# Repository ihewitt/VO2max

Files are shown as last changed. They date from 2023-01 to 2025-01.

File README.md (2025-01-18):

# VO₂max
Code and build files for Rabbitcreek's VO₂Max Spirometer. _Incorporating CO₂ enhancements from Ulrich Rissel._
Build instructions on [Instructable](https://www.instructables.com/Accurate-VO2-Max-for-Zwift-and-Strava/)
See Nik's pages for excellent build details: [meteoscientific](https://github.com/meteoscientific/VO2max)

Source code for Arduino under "VO₂Max" - Arduino board settings to use for TTGO T-Display:

    Board: ESP32 Dev Module
    Upload Speed: 921600
    CPU Frequency: 240Mhz (WiFi/BT)
    Flash Frequency: 80Mhz
    Flash Mode: QIO
    Flash Size: 4MB (32Mb)
    Partition Scheme: Huge APP (3MB No OTA/1MB SPIFFS)
    Core Debug Level: None
    PSRAM: Disabled

<figure>
    Build parts
    <figcaption>Source parts, top to bottom. 3M mask with front plate removed, 3D printed case, Oxygen sensor, TTGo T-Display, Flow sensor.</figcaption>
</figure><br><br>
<figure>
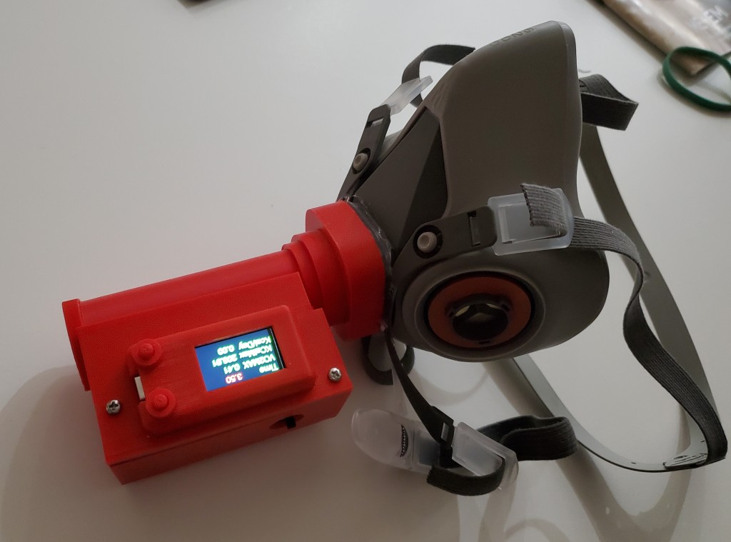
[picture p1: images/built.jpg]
First build
    
    <figcaption>First finished build.</figcaption>
</figure><br><br>
<figure>
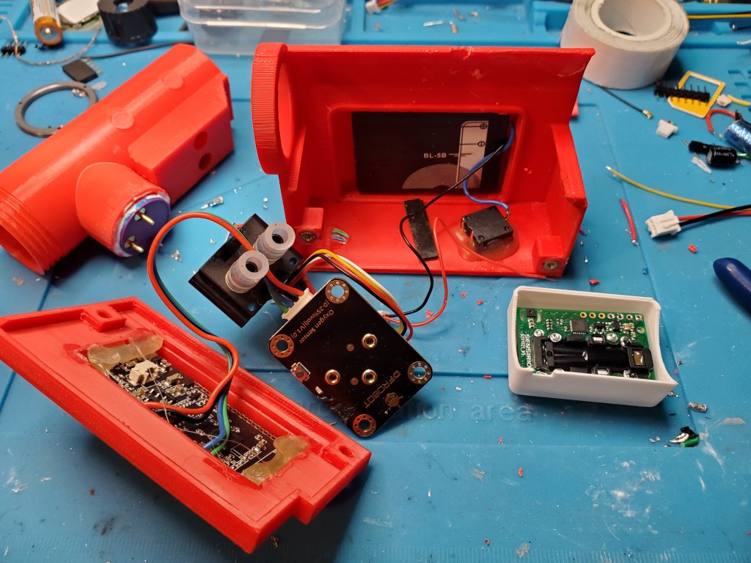
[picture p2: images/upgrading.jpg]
Upgrading
    
    <figcaption>Rebuilding to use CO₂ sensor. SCD30 pictured right.</figcaption>
</figure><br><br>
<figure>
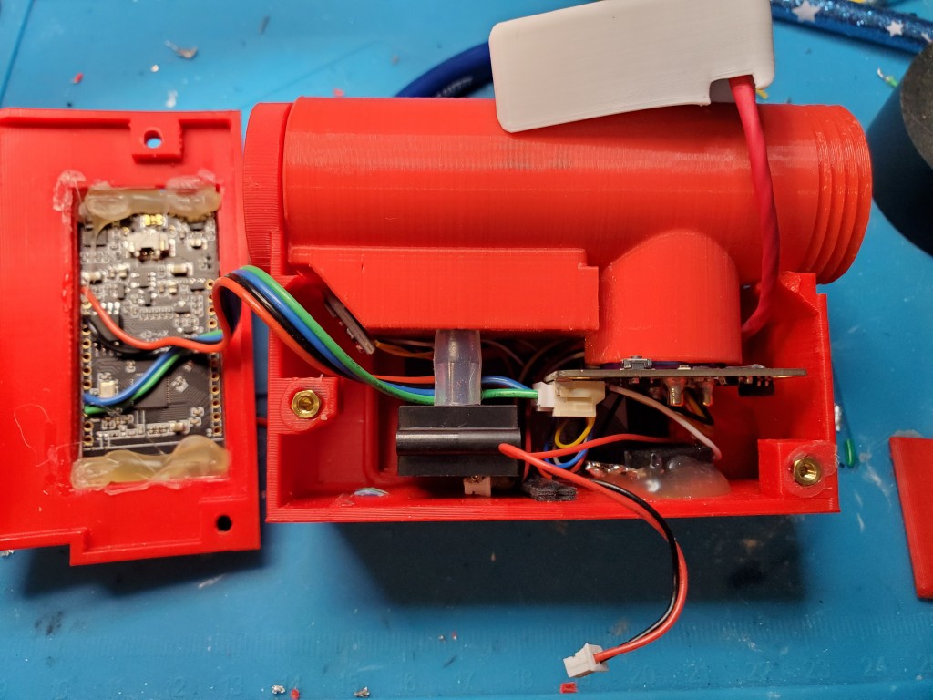
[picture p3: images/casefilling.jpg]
    
    <figcaption>Assembled into case tightly, BM280 barometer addition mounted onto front of tube, wiring for CO₂ monitor fed behind and out to top.</figcaption>
</figure><br><br>
<figure>
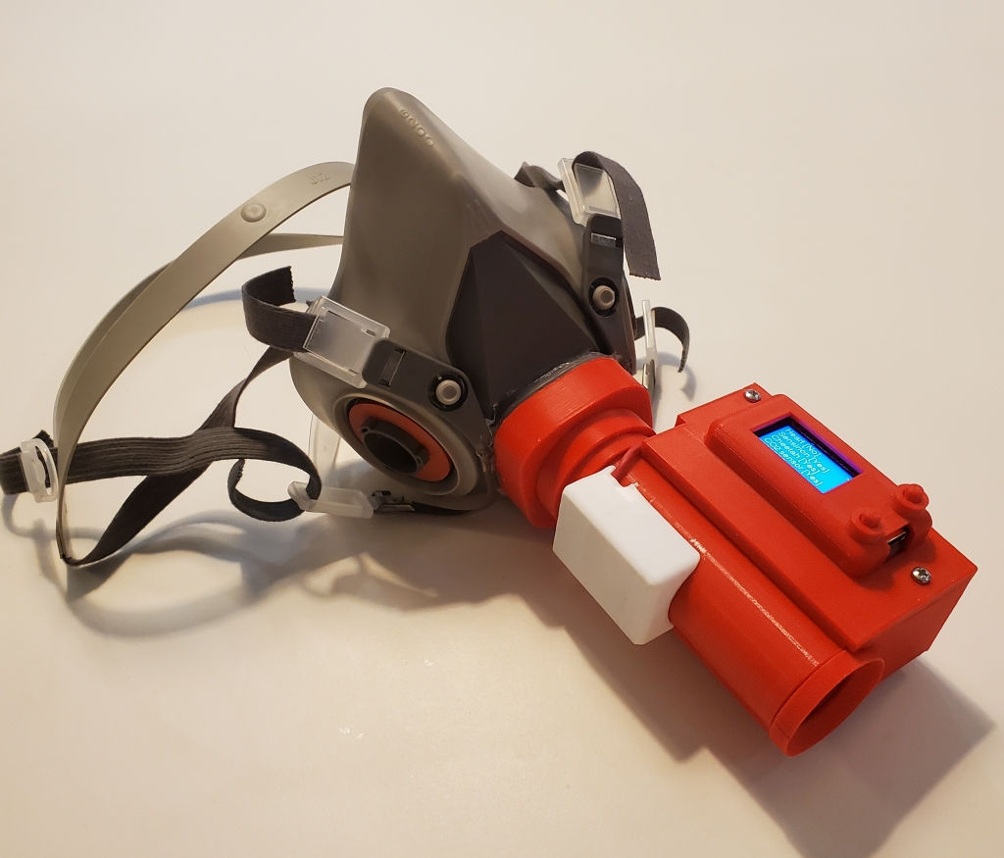
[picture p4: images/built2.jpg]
    
    <figcaption>Pictured with the CO₂ sensor upgrade attached</figcaption>
</figure><br><br>

3D printing files are within the `design` folder, Ulrich Rissel's design files to use a larger venturi diameter with CO₂ sensor holder in `design/CO2_upgrade`

Additional changes in this version:
- Menu system enhanced with adjustable calibration and setup options.
- Additional GoldenCheetah integration (with VO₂ master output)
- CO₂ sensor support (Ulrich's mods)
- STC31 CO₂ sensor support
- Ability to run without O₂ sensor

More notes on the CO₂ sensor use can be found at: [CO₂ sensors](https://blog.ivor.org/2024/12/carbon-dioxide.html)
Details of the interface: [Screens](docs/screens.md)

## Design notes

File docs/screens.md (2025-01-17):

The initial menu:
VO2 screens
Lets you configure basic options, it's important to get the flow sensor calibration checked/set correctly (see [Calibration](calibration.md))
Setting the weight is necessary to get valid VO2 calculations.
Clicking "+" will move between options, ">" will select items.

After closing the menu the summary page is displayed to confirm sensible starting data, Co2 should be reading zero and O2 ~21% at startup.
summary

When running the buttons will loop up and down through the pages, holding both buttons together will reset and return back to the initial menu.

Screen1:



Screen2:



Screen3:



Screen4:



Screen5:



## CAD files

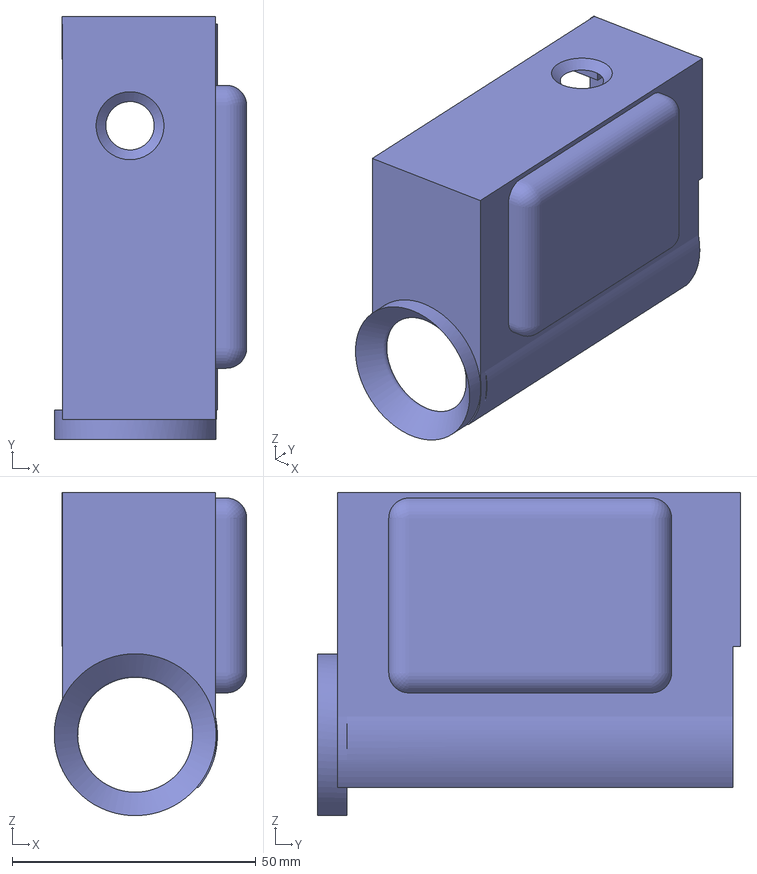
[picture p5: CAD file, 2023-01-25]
design/MainBody.3mf
39.5 x 86.8 x 66.3 mm

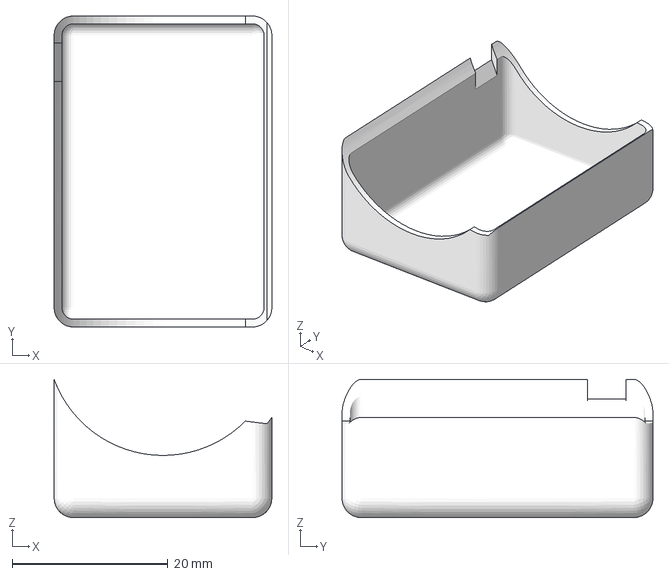
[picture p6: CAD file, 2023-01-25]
design/CO2_upgrade/SCD30 Cover.3mf
28.0 x 40.0 x 17.8 mm

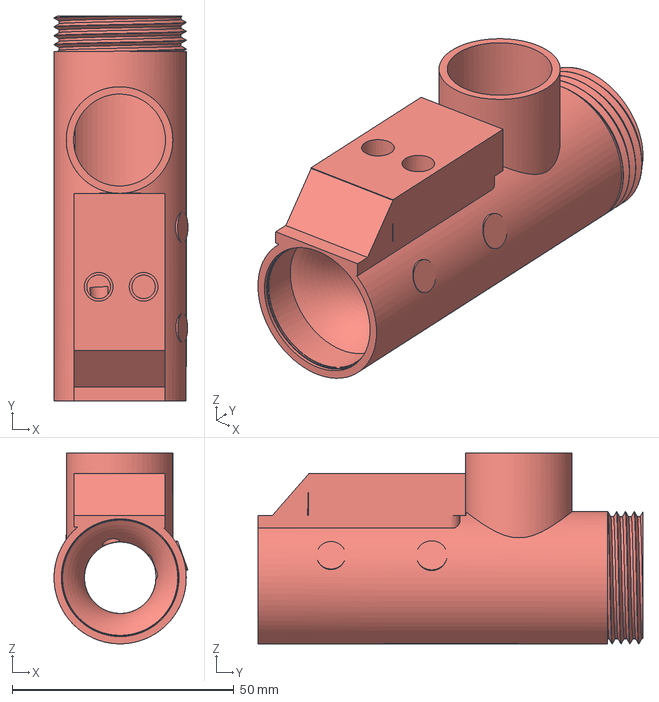
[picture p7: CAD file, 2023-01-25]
design/VenturiSensor.3mf
30.2 x 86.8 x 43.0 mm

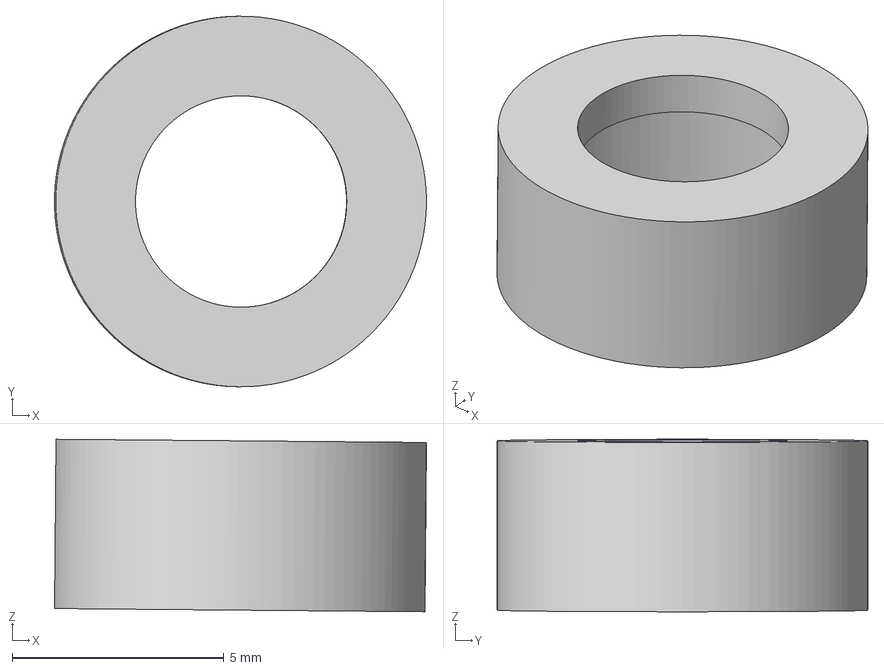
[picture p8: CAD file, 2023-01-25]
design/buttonHousing.3mf
8.79 x 8.75 x 4.08 mm

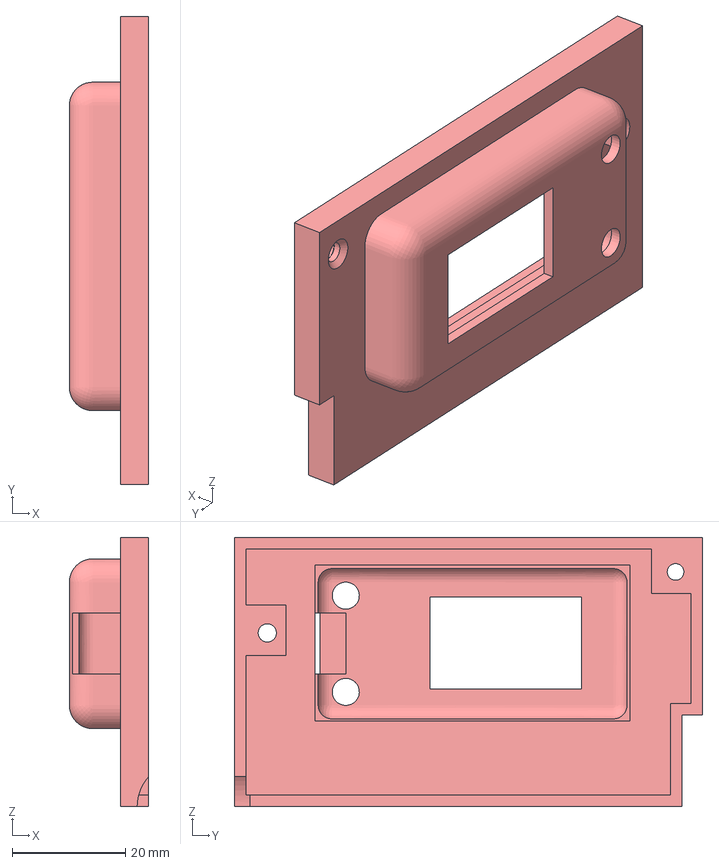
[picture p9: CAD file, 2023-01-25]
design/SideComputer.3mf
14.0 x 82.6 x 47.6 mm

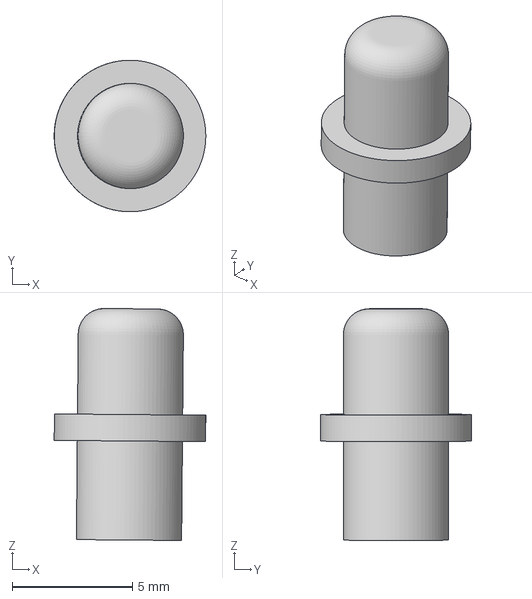
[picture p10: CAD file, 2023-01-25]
design/button.3mf
6.31 x 6.30 x 9.66 mm

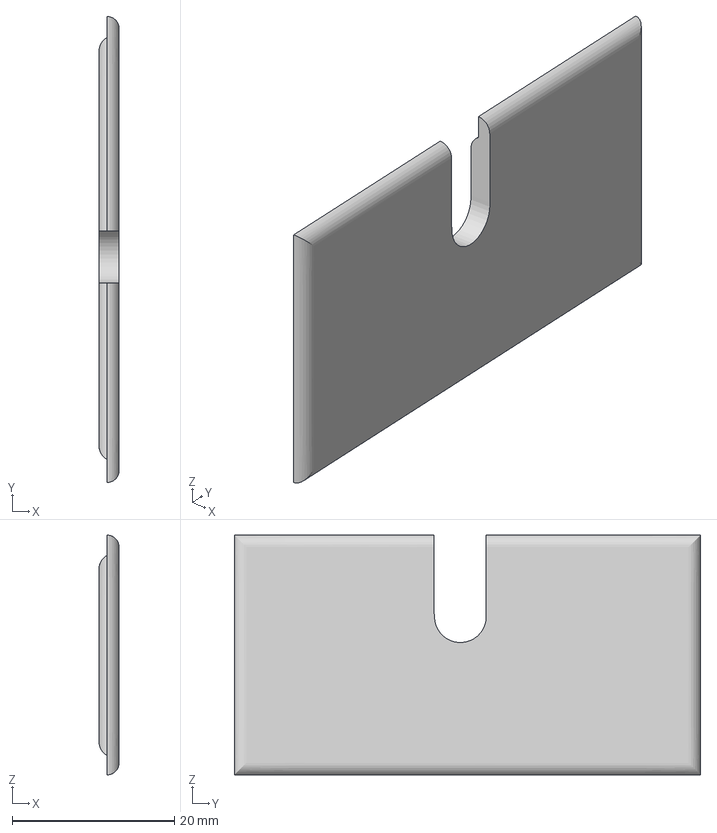
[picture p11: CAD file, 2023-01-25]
design/ComputerCover.3mf
2.49 x 57.5 x 29.6 mm

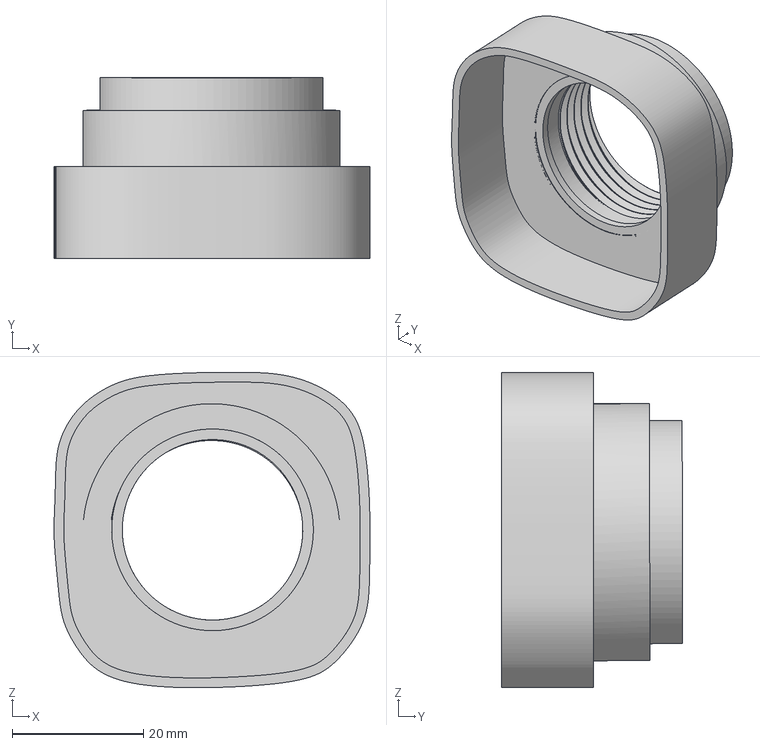
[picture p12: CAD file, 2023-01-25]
design/MaskAttachment.3mf
48.2 x 27.7 x 48.2 mm

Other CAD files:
design/CO2_upgrade/Venturi CO2 20mm.3mf
design/CO2_upgrade/Venturi CO2 16mm.3mf

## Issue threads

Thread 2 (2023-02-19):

change SCD30 for diffrent sensor

smalecki, 2023-02-19:
Co2 sensor SCD30 have not enough range. 40000 ppm is 4%. During exhale without exercise we have about 3-4%. During exercise is more than 4%.
Don't found replacement for that for now.

ihewitt, 2023-02-19:
yeah although the CO2 sensor isn't crucial to getting the VO2 max calculation and is just providing some additional resp data. Also I think it improves the calculation since it can be used to provide the values for the respired air temperature and humidity. (although obviously these aren't wildly variable and probably doesn't improve much over having hardcoded defaults)
and as you say I also didn't see any suitable replacement either.

ihewitt, 2024-02-05:
Thanks, yeah I can't see anything small enough or cheap enough to make sense anywhere.
(finally got around to taking a look at this again! 🙂)

ihewitt, 2024-02-12:
FYI switched to a ENS160 (with AN41) to test and it no longer maxes out, but doesn't seem to give values high enough for the exhaled air.
I'll test a little more, but I don't think the CO2 sensor (either) is of much use really.

ihewitt, 2024-02-27:
Ongoing - more co2 sensors on way, will update site with details after building/testing.

ihewitt, 2024-03-14:
FYI I added some notes about using a different sensor here (and uploaded the code - https://github.com/ihewitt/VO2max/commit/3321b3691952aad3dd693bd3de983f4fc1948c81)
Notes - https://blog.ivor.org/2024/03/the-ongoing-vo2-max-saga.html
I'll add the details to this repo also.

Closed 2024-02-27.

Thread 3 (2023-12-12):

Issues with the code

brunodom, 2023-12-12:
Hi @ihewitt , I am trying to follow your instruction and I am using Arduino IDE 2.2.1 on Win11. I have installed the ESP32 Dev Module and using the parameters in your source code. However, I am getting these errors on the compilation:

In file included from C:\Users\bruno\OneDrive\Projects\Training Insights\VO2Max\VO2Max-alternative\VO2max-main\VO2max\VO2max.ino:37:
c:\Users\bruno\OneDrive\Documents\Arduino\libraries\TFT_eSPI/TFT_eSPI.h:973:8: warning: #warning >>>>------>> TOUCH_CS pin not defined, TFT_eSPI touch functions will not be available! [-Wcpp]
       #warning >>>>------>> TOUCH_CS pin not defined, TFT_eSPI touch functions will not be available!
        ^~~~~~~
C:\Users\bruno\OneDrive\Projects\Training Insights\VO2Max\VO2Max-alternative\VO2max-main\VO2max\VO2max.ino:985:57: warning: ISO C++ forbids converting a string constant to 'char*' [-Wwrite-strings]
                         {icount++, "Done.", false, 0, 0}};
                                                         ^
C:\Users\bruno\OneDrive\Projects\Training Insights\VO2Max\VO2Max-alternative\VO2max-main\VO2max\VO2max.ino:985:57: warning: ISO C++ forbids converting a string constant to 'char*' [-Wwrite-strings]
C:\Users\bruno\OneDrive\Projects\Training Insights\VO2Max\VO2Max-alternative\VO2max-main\VO2max\VO2max.ino:985:57: warning: ISO C++ forbids converting a string constant to 'char*' [-Wwrite-strings]
C:\Users\bruno\OneDrive\Projects\Training Insights\VO2Max\VO2Max-alternative\VO2max-main\VO2max\VO2max.ino:985:57: warning: ISO C++ forbids converting a string constant to 'char*' [-Wwrite-strings]
C:\Users\bruno\OneDrive\Projects\Training Insights\VO2Max\VO2Max-alternative\VO2max-main\VO2max\VO2max.ino:985:57: warning: ISO C++ forbids converting a string constant to 'char*' [-Wwrite-strings]
C:\Users\bruno\OneDrive\Projects\Training Insights\VO2Max\VO2Max-alternative\VO2max-main\VO2max\VO2max.ino:985:57: warning: ISO C++ forbids converting a string constant to 'char*' [-Wwrite-strings]
C:\Users\bruno\OneDrive\Projects\Training Insights\VO2Max\VO2Max-alternative\VO2max-main\VO2max\VO2max.ino:985:57: warning: ISO C++ forbids converting a string constant to 'char*' [-Wwrite-strings]
C:\Users\bruno\OneDrive\Projects\Training Insights\VO2Max\VO2Max-alternative\VO2max-main\VO2max\VO2max.ino:985:57: warning: ISO C++ forbids converting a string constant to 'char*' [-Wwrite-strings]
C:\Users\bruno\OneDrive\Projects\Training Insights\VO2Max\VO2Max-alternative\VO2max-main\VO2max\VO2max.ino: In function 'void doMenu()':
C:\Users\bruno\OneDrive\Projects\Training Insights\VO2Max\VO2Max-alternative\VO2max-main\VO2max\VO2max.ino:1020:18: error: variable 'sel' set but not used [-Werror=unused-but-set-variable]
             bool sel;
                  ^~~
C:\Users\bruno\OneDrive\Projects\Training Insights\VO2Max\VO2Max-alternative\VO2max-main\VO2max\VO2max.ino:1048:23: error: format '%d' expects argument of type 'int', but argument 5 has type 'void (*)()' [-Werror=format=]
         Serial.printf("cur %d, %d, %d", cur, menuitems[cur].toggle, menuitems[cur].fn);
                       ^~~~~~~~~~~~~~~~                              ~~~~~~~~~~~~~~~~~
C:\Users\bruno\OneDrive\Projects\Training Insights\VO2Max\VO2Max-alternative\VO2max-main\VO2max\VO2max.ino: In function 'void tftScreen4()':
C:\Users\bruno\OneDrive\Projects\Training Insights\VO2Max\VO2Max-alternative\VO2max-main\VO2max\VO2max.ino:1208:11: error: unused variable 'co2diff' [-Werror=unused-variable]
     float co2diff = lastO2 - initialO2;
           ^~~~~~~
cc1plus.exe: some warnings being treated as errors

Are you getting the same result? any clue on what is wrong?

kongmu511, 2023-12-12:
some T-display is diffrent, try the TFT_eSPI library in their GitHub repo, https://github.com/Xinyuan-LilyGO/TTGO-T-Display/tree/master/TFT_eSPI

brunodom, 2023-12-12:
@kongmu511 thanks, but didn't work. I tried in the past and tried it again just to capture the error:

-----------
C:\Users\bruno\OneDrive\Projects\Training Insights\VO2Max\VO2Max-alternative\VO2max-main\VO2max\VO2max.ino:985:57: warning: ISO C++ forbids converting a string constant to 'char*' [-Wwrite-strings]
                         {icount++, "Done.", false, 0, 0}};
                                                         ^
C:\Users\bruno\OneDrive\Projects\Training Insights\VO2Max\VO2Max-alternative\VO2max-main\VO2max\VO2max.ino:985:57: warning: ISO C++ forbids converting a string constant to 'char*' [-Wwrite-strings]
C:\Users\bruno\OneDrive\Projects\Training Insights\VO2Max\VO2Max-alternative\VO2max-main\VO2max\VO2max.ino:985:57: warning: ISO C++ forbids converting a string constant to 'char*' [-Wwrite-strings]
C:\Users\bruno\OneDrive\Projects\Training Insights\VO2Max\VO2Max-alternative\VO2max-main\VO2max\VO2max.ino:985:57: warning: ISO C++ forbids converting a string constant to 'char*' [-Wwrite-strings]
C:\Users\bruno\OneDrive\Projects\Training Insights\VO2Max\VO2Max-alternative\VO2max-main\VO2max\VO2max.ino:985:57: warning: ISO C++ forbids converting a string constant to 'char*' [-Wwrite-strings]
C:\Users\bruno\OneDrive\Projects\Training Insights\VO2Max\VO2Max-alternative\VO2max-main\VO2max\VO2max.ino:985:57: warning: ISO C++ forbids converting a string constant to 'char*' [-Wwrite-strings]
C:\Users\bruno\OneDrive\Projects\Training Insights\VO2Max\VO2Max-alternative\VO2max-main\VO2max\VO2max.ino:985:57: warning: ISO C++ forbids converting a string constant to 'char*' [-Wwrite-strings]
C:\Users\bruno\OneDrive\Projects\Training Insights\VO2Max\VO2Max-alternative\VO2max-main\VO2max\VO2max.ino:985:57: warning: ISO C++ forbids converting a string constant to 'char*' [-Wwrite-strings]
C:\Users\bruno\OneDrive\Projects\Training Insights\VO2Max\VO2Max-alternative\VO2max-main\VO2max\VO2max.ino: In function 'void doMenu()':
C:\Users\bruno\OneDrive\Projects\Training Insights\VO2Max\VO2Max-alternative\VO2max-main\VO2max\VO2max.ino:1020:18: error: variable 'sel' set but not used [-Werror=unused-but-set-variable]
             bool sel;
                  ^~~
C:\Users\bruno\OneDrive\Projects\Training Insights\VO2Max\VO2Max-alternative\VO2max-main\VO2max\VO2max.ino:1048:23: error: format '%d' expects argument of type 'int', but argument 5 has type 'void (*)()' [-Werror=format=]
         Serial.printf("cur %d, %d, %d", cur, menuitems[cur].toggle, menuitems[cur].fn);
                       ^~~~~~~~~~~~~~~~                              ~~~~~~~~~~~~~~~~~
C:\Users\bruno\OneDrive\Projects\Training Insights\VO2Max\VO2Max-alternative\VO2max-main\VO2max\VO2max.ino: In function 'void tftScreen4()':
C:\Users\bruno\OneDrive\Projects\Training Insights\VO2Max\VO2Max-alternative\VO2max-main\VO2max\VO2max.ino:1208:11: error: unused variable 'co2diff' [-Werror=unused-variable]
     float co2diff = lastO2 - initialO2;
           ^~~~~~~
cc1plus.exe: some warnings being treated as errors
Multiple libraries were found for "TFT_eSPI.h"
  Used: C:\Users\bruno\OneDrive\Documents\Arduino\libraries\TFT_eSPI
  Not used: C:\Users\bruno\OneDrive\Documents\Arduino\libraries\TFT_eSPI_OLD

---------

As you can see, I renamed the folder to _OLD and copied from the TFT_eSPI from the git repository, it used the correct one but with the same outcome. :(

Do you have it working? can you share the file and the libraries (or at least the version) to make sure that is not a problem on my side.

kongmu511, 2023-12-12:
we usally compile and program using Arduino 1.8.5

brunodom, 2023-12-12:
> we usally compile and program using Arduino 1.8.5

Just tried with Arduino IDE 1.8.9 and same result:

C:\Users\bruno\OneDrive\Documents\Arduino\libraries\Omron_D6F-PH_Arduino_Library\src\Omron_D6FPH.cpp: In member function 'boolean Omron_D6FPH::init()':
C:\Users\bruno\OneDrive\Documents\Arduino\libraries\Omron_D6F-PH_Arduino_Library\src\Omron_D6FPH.cpp:56:42: error: 'I2C_ERROR_OK' was not declared in this scope
   return (_i2cPort->endTransmission() == I2C_ERROR_OK);
                                          ^~~~~~~~~~~~
C:\Users\bruno\OneDrive\Documents\Arduino\libraries\Omron_D6F-PH_Arduino_Library\src\Omron_D6FPH.cpp: In member function 'boolean Omron_D6FPH::isConnected()':
C:\Users\bruno\OneDrive\Documents\Arduino\libraries\Omron_D6F-PH_Arduino_Library\src\Omron_D6FPH.cpp:61:43: error: 'I2C_ERROR_OK' was not declared in this scope
     return _i2cPort->endTransmission() == I2C_ERROR_OK;
                                           ^~~~~~~~~~~~
C:\Users\bruno\OneDrive\Documents\Arduino\libraries\Omron_D6F-PH_Arduino_Library\src\Omron_D6FPH.cpp: In member function 'boolean Omron_D6FPH::executeMcuMode()':
C:\Users\bruno\OneDrive\Documents\Arduino\libraries\Omron_D6F-PH_Arduino_Library\src\Omron_D6FPH.cpp:75:42: error: 'I2C_ERROR_OK' was not declared in this scope
   return (_i2cPort->endTransmission() == I2C_ERROR_OK);
                                          ^~~~~~~~~~~~
C:\Users\bruno\OneDrive\Documents\Arduino\libraries\Omron_D6F-PH_Arduino_Library\src\Omron_D6FPH.cpp: In member function 'float Omron_D6FPH::getPressure()':
C:\Users\bruno\OneDrive\Documents\Arduino\libraries\Omron_D6F-PH_Arduino_Library\src\Omron_D6FPH.cpp:86:44: error: 'I2C_ERROR_OK' was not declared in this scope
         if (_i2cPort->endTransmission() == I2C_ERROR_OK){
                                            ^~~~~~~~~~~~
C:\Users\bruno\OneDrive\Documents\Arduino\libraries\Omron_D6F-PH_Arduino_Library\src\Omron_D6FPH.cpp: In member function 'float Omron_D6FPH::getTemperature()':
C:\Users\bruno\OneDrive\Documents\Arduino\libraries\Omron_D6F-PH_Arduino_Library\src\Omron_D6FPH.cpp:104:44: error: 'I2C_ERROR_OK' was not declared in this scope
         if (_i2cPort->endTransmission() == I2C_ERROR_OK){
                                            ^~~~~~~~~~~~
C:\Users\bruno\OneDrive\Documents\Arduino\libraries\Omron_D6F-PH_Arduino_Library\src\Omron_D6FPH.cpp: In member function 'boolean Omron_D6FPH::readRegister(uint8_t, uint16_t*)':
C:\Users\bruno\OneDrive\Documents\Arduino\libraries\Omron_D6F-PH_Arduino_Library\src\Omron_D6FPH.cpp:118:39: error: 'I2C_ERROR_OK' was not declared in this scope
     if(_i2cPort->endTransmission() == I2C_ERROR_OK){
                                       ^~~~~~~~~~~~

It is interesting that even with the Omron_D6F-PH example I got the same error.

ihewitt, 2024-02-27:
I assume this is cleared now? The earlier errors appear to be the compiler is set to warnings on and warnings as errors, and looks like the original code isn't warning clear.
Changing the ide/compile settings to not fail on warnings should clear that until they are fixed in that code.
Clearly the second error if the omron example is failing, looks like there must be missing base dependencies somehow.

Closed 2024-03-13.

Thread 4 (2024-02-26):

doubt about co2 hole

IOSUT, 2024-02-26:
Thanks for your contribution, I´m trying to upgrade the first version heloig with Venturi´s CO2 update, and my doubt is:

need I  to fill the cover of Co2 with glue to not enable to pass O2 trought them to exterior? I´m assuming with this that the co2 hole maybe will affect to Bernoulli formule, V and pressure, but maybe the code incliudes it?

Sorry for my ignorance, thanks.

ihewitt, 2024-02-27:
Firstly, at the moment it's probably not worth making the co2 modification until we can find/decide a suitable co2 sensor. the SCD30 maxes out at 4% which is hit easily during exercise, so doesn't really provide much useful information.
But if you are adding one, do you have the additional small case to mount externally? If so then the only thing I used was a small filter (cut from a facemask) to cover the hole externally underneath the co2 sensor and case.

IOSUT, 2024-02-29:
Thanks, I have the cover yes, I´m thinking maybe to use the Co2 values to estimate Fatmax, using lower values to limit of 4% of measurement that you said.

Thanks!

Closed 2024-02-27.

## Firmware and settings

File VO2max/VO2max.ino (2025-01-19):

//+++++++++++++++++++++++++++++++++++++++++++++++++++++++++++++++
// Spirometrie Project
// https://www.instructables.com/Accurate-VO2-Max-for-Zwift-and-Strava/
// BLE by Andreas Spiess https://github.com/SensorsIot/Bluetooth-BLE-on-Arduino-IDE
// Modifications by Ulrich Rissel and Ivor Hewitt
//
// TTGO T-Display: SDA-Pin21, SCL-Pin22
//+++++++++++++++++++++++++++++++++++++++++++++++++++++++++++++++

const String Version = "V2.5.2 2025/01/17";

/*Board: ESP32 Dev Module
Upload Speed: 921600
CPU Frequency: 240Mhz (WiFi/BT)
Flash Frequency: 80Mhz
Flash Mode: QIO
Flash Size: 4MB (32Mb)
Partition Scheme: Huge APP (3MB No OTA/1MB SPIFFS)
Core Debug Level: None
PSRAM: Disabled*/

// Libraries:
//   Sensirion_I2C_STC3x : 1.0.1
//   SparkFun_SHTC3_Humidity_and_Temperature_Sensor_Library : 1.1.4
//   Omron_D6F-PH_Arduino_Library : 1.1.0
//   TFT_eSPI : 2.5.43
//   Adafruit_BME280_Library : 2.2.4
//   Adafruit_BMP085_Library : 1.2.4
//   Adafruit_BMP280_Library : 2.6.8
//   Sensirion_Gadget_BLE_Arduino_Lib : 1.4.1
//   NimBLE-Arduino : 2.1.2
//   DFRobot_OxygenSensor : 1.0.1

/* Note: In  Arduino/libraries/TFT_eSPI/User_Setup_Select.h
 * make sure to uncomment the t-display driver line (Setup25) */

/// ############################################################################################
/// MACROS TO BE DEFINED IN CONFIG.H
/// ############################################################################################
#include "config.h"

#include "esp_adc_cal.h" // ADC calibration data
#include <EEPROM.h>      // include library to read and write settings from flash
#define ADC_EN  14       // ADC_EN is the ADC detection enable port
#define ADC_PIN 34
int vref = 1100;

#ifdef OXYSENSOR
#include "DFRobot_OxygenSensor.h" //Library for Oxygen sensor
#elif !defined(STC_31) && !defined(SCD_30)
#error "A CO2 sensor must be enabled if no OXY sensor"
#endif

#ifdef SCD_30      // original SCD_30 sensor (inadequate - max 4% co2)
#include "SCD30.h" //declares "SCD_30 scd30"
#elif defined(STC_31)
#include "SensirionI2cStc3x.h" //Use Sensirion library
SensirionI2cStc3x stc3x_sensor;
#include "SparkFun_SHTC3.h"    //Use sparkfun shtc3 library
SHTC3             mySHTC3;
#endif

#include "hal/gpio_ll.h"
#include <Omron_D6FPH.h> //Library for pressure sensor
#include <SPI.h>
#include <TFT_eSPI.h> // Graphics and font library for ST7735 driver chip, see note above (line 20)
#include <Wire.h>

// NOTE: If GadgetBLE doesn't compile because of setMinPreferred/MaxPreferred removed,
// replace GadgetBLE code with:
// _data->pNimBLEAdvertising->setPreferredParams(0x06, 0x12);
#ifdef GADGET
#include "Sensirion_Gadget_BLE.h" //library to publish to Sensirion 'gadget' App
#endif

// declarations for bluetooth serial --------------
#include "BluetoothSerial.h"
#if !defined(CONFIG_BT_ENABLED) || !defined(CONFIG_BLUEDROID_ENABLED)
#error Bluetooth is not enabled! Please run `make menuconfig` to and enable it
#endif
BluetoothSerial SerialBT;

// declarations for BLE ---------------------
#include <BLE2902.h> // used for notifications 0x2902: Client Characteristic Configuration
#include <BLEDevice.h>
#include <BLEServer.h>
#include <BLEUtils.h>

byte bpm;
byte heart[8] = {0b00001110, 60, 0, 0, 0, 0, 0, 0}; // defines the BT heartrate characteristic

// Byte[0]: flags: 0b00001110:
// not used/n.u./n.u./RR value available/Energy val.av./
// Sensor contact status/Sens.cont.supported/HR Format: (0: uint_8)
// Byte[1]: HR (uint_8)
// Byte[2]: Energy in J MSB
// Byte[3]: Energy in J LSB
// Byte[4]: RR
// Byte[5]: RR
// Byte[6]: ?
// Byte[7]: ?

byte hrmPos[1] = {2};

bool _BLEClientConnected = false;

#define batteryLevelServiceId BLEUUID((uint16_t)0x180F)
BLECharacteristic batteryLevelCharacteristics(BLEUUID((uint16_t)0x2A19),
                                              BLECharacteristic::PROPERTY_READ | BLECharacteristic::PROPERTY_NOTIFY);

// heart rate service
#define heartRateService BLEUUID((uint16_t)0x180D)
BLECharacteristic heartRateMeasurementCharacteristics(BLEUUID((uint16_t)0x2A37), BLECharacteristic::PROPERTY_NOTIFY);
BLECharacteristic sensorPositionCharacteristic(BLEUUID((uint16_t)0x2A38), BLECharacteristic::PROPERTY_READ);
BLEDescriptor     heartRateDescriptor(BLEUUID((uint16_t)0x2901));
BLEDescriptor     sensorPositionDescriptor(BLEUUID((uint16_t)0x2901)); // 0x2901: Characteristic User Description

struct {
    uint16_t feo2;
    uint16_t feco2;
    uint16_t vo2;
    uint16_t vco2;
} cheetGas;

struct {
    uint16_t rf;
    uint16_t tidal;
    uint16_t rmv;
} cheetVent;

struct {
    uint16_t pressure;
    uint16_t temp;
    uint16_t hum;
    uint16_t o2;
    uint16_t unused;
} cheetEnv;

// GoldenCheetah service
// Publish to GoldenCcheetah using the 'vo2master' device characteristics
#define cheetahService BLEUUID("00001523-1212-EFDE-1523-785FEABCD123")

#define nameService BLEUUID((uint16_t)0x180A)
BLECharacteristic nameCharacteristics(BLEUUID((uint16_t)0x2A24), BLECharacteristic::PROPERTY_READ);

// Use new format to add ventilatory and co2 info
BLECharacteristic cheetahIn(BLEUUID("00001525-1212-EFDE-1523-785FEABCD123"), //
                            BLECharacteristic::PROPERTY_WRITE);
BLECharacteristic cheetahOut(BLEUUID("00001526-1212-EFDE-1523-785FEABCD123"), //
                             BLECharacteristic::PROPERTY_READ | BLECharacteristic::PROPERTY_NOTIFY);

BLEDescriptor cheetahOutDescriptor(BLEUUID((uint16_t)0x0100)); //? cheetah has this?

BLECharacteristic cheetahVent(BLEUUID("00001527-1212-EFDE-1523-785FEABCD123"), //
                              BLECharacteristic::PROPERTY_NOTIFY);

BLECharacteristic cheetahGas(BLEUUID("00001528-1212-EFDE-1523-785FEABCD123"), //
                             BLECharacteristic::PROPERTY_NOTIFY);

BLECharacteristic cheetahEnv(BLEUUID("00001529-1212-EFDE-1523-785FEABCD123"), //
                             BLECharacteristic::PROPERTY_NOTIFY);

class MyServerCallbacks : public BLEServerCallbacks {
    void onConnect(BLEServer *pServer) { _BLEClientConnected = true; };

    void onDisconnect(BLEServer *pServer) {
        BLEDevice::startAdvertising();
        _BLEClientConnected = false;
    }
};

class MyCallbacks : public BLECharacteristicCallbacks {
    void onWrite(BLECharacteristic *pCharacteristic) {
        String rxValue = pCharacteristic->getValue();

        if (rxValue.length() >= 2) {
            uint8_t command = rxValue[0];
            uint8_t value = rxValue[1];
            Serial.printf("Cmd %02x, Val %02x\n", command, value);
        }
    }
};

#if defined(BMP085)
#include <Adafruit_BMP085.h> //Library for barometric sensor
Adafruit_BMP085 bmp;
#elif defined(BME280)
#include <Adafruit_BME280.h> //Library for barometric sensor
Adafruit_BME280 bmp;
#elif defined(BMP280)
#include <Adafruit_BMP280.h> //Library for barometric sensor
Adafruit_BMP280 bmp;
#endif

bool co2Enabled = false;
bool bmpEnabled = false;

// Starts Screen for TTGO device
TFT_eSPI tft = TFT_eSPI(); // Invoke library, pins defined in User_Setup.h

// Labels the pressure sensor: mySensor
Omron_D6FPH mySensor;

// Label of oxygen sensor
#ifdef OXYSENSOR
DFRobot_OxygenSensor Oxygen;
#define COLLECT_NUMBER    10        // collect number, the collection range is 1-100.
#define Oxygen_IICAddress ADDRESS_3 // I2C  label for o2 address
#endif

// Defines button state for adding wt
const int buttonPin1 = 0;
const int buttonPin2 = 35;
int       wtTotal = 0;
int       buttonPushCounter1 = 0; // counter for the duration of button1 pressed
int       buttonState1 = 1;       // current state of the button
int       buttonPushCounter2 = 0; // counter for the duration of button2 pressed
int       buttonState2 = 1;       // current state of the button
int       screenChanged = 0;
int       screenNr = 1;
int       HeaderStreamed = 0;
int       HeaderStreamedBT = 0;

// ############################################
//  Select correct diameter depending on printed
//  case dimensions:
// ############################################

// Defines the size of the Venturi openings for the  calculations of AirFlow
const float area_1 = 0.000531; // = 26mm diameter
#if (DIAMETER == 20)
const float area_2 = 0.000314; // = 20mm diameter
#elif (DIAMETER == 19)
const float area_2 = 0.000284; // = 19mm diameter
#else // default
const float area_2 = 0.000201; // = 16mm diameter
#endif

// Air density values
const float dryConstant = 287.058;
const float wetConstant = 461.495;

// Sensible defaults to use with no barometers
const float rhoSTPD = 1.292; // STPD conditions: density at 0°C, MSL, 1013.25 hPa, dry air
float       rhoATPS = 1.225; // ATP conditions: density based on ambient conditions, dry air
float       rhoBTPS = 1.123; // BTPS conditions: density at ambient  pressure, 35°C, 95% humidity

// Alternative ATPS for room temperature - 20c, 50% = 1.199

// Default ambient values for standard ATPS
float TempC = 15.0;    // Air temperature in Celsius
float PresPa = 101325; // uncorrected (absolute) barometric pressure
float Humid = 0;       // dry air

float massFlow = 0.0;
float volFlow = 0.0;
float volumeTotal = 0.0;    // variable for holding total volume of breath
float pressure = 0.0;       // differential pressure of the venturi nozzle
float pressThreshold = 0.2; // threshold for starting calculation of VE
float volumeVE = 0.0;
float volumeVEmean = 0.0;
float volumeExp = 0.0;
float BPM = 0.0;

// Basic defaults in settings, saved to eeprom
struct {
    int   version = 2;            // Make sure saved data is right version
    float correctionSensor = 1.0; // calculated from 3L calibration syringe
    float weightkg = 75.0;        // Standard-body-weight
    bool  heart_on = false;       // Output vo2 as a HRM
    bool  sens_on = true;         // Output as sensiron data
    bool  serialbt = false;       // Send detail over Serial Bluetooth
    bool  cheet_on = false;       // Output as vo2master for GoldenCheetah
    bool  co2_on = false;         // CO2 sensor active
} settings;

unsigned long TimerVolCalc = 0;
unsigned long Timer5s = 0;
unsigned long Timer30s = 0;
unsigned long TimerVO2calc = 0;
unsigned long TimerVO2diff = 0; // used for integral of calories
unsigned long TimerStart = 0;
unsigned long TotalTime = 0;
String        TotalTimeMin = String("00:00");
int           readVE = 0;
unsigned long TimerVE = 0;
unsigned long DurationVE = 0;

float lastO2 = 0;
float baselineO2 = 0;
float co2 = 0;
float calTotal = 0;
float vo2Cal = 0;
float vo2CalH = 0;        // calories per hour
float vo2CalDay = 0.0;    // calories per day
float vo2CalDayMax = 0.0; // highest value of calories per day
float vo2Max = 0;         // value of vo2Max/min/kg, calculated every 30 seconds
float vo2Total = 0.0;     // value of total vo2Max/min
float vo2MaxMax = 0;      // Best value of vo2 max for whole time machine is on

float respq = 0.0; // respiratory quotient in mol VCO2 / mol VO2

#ifdef SCD_30
float co2ppm = 0.0; // CO2 sensor in ppm
#endif

float co2perc = 0.0;     // = CO2ppm /10000
float baselineCO2 = 0.0; // initial value of CO2 in ppm
float vco2Total = 0.0;
float vco2Max = 0.0;
float co2temp = 0.0; // temperature CO2 sensor
float co2hum = 0.0;  // humidity CO2 sensor (not used in calculations)

float freqVE = 0.0;     // ventilation frequency
float freqVEmean = 0.0; // mean ventilation frequency

float expiratVol = 0.0; // last expiratory volume in L
float volumeTotalOld = 0.0;
float volumeTotal2 = 0.0;

float Battery_Voltage = 0.0;

// settings for Sensirion App
#ifdef GADGET
NimBLELibraryWrapper lib;
DataProvider         provider(lib, DataType::T_RH_CO2_ALT);
#endif

// STC_31 calc
#ifdef STC_31
static float frcReferenceValue = 0.0;
uint16_t     signalRawGasConcentration(float gasConcentration) { return (uint16_t)gasConcentration * 327.68 + 16384.0; }
#endif

//----------------------------------------------------------------------------------------------------------
//                  SETUP
//----------------------------------------------------------------------------------------------------------

void loadSettings() {
    // Check version first.
    int version = EEPROM.read(0);
    if (version == settings.version) {
        for (int i = 0; i < sizeof(settings); ++i)
            ((byte *)&settings)[i] = EEPROM.read(i);
    }
}

void saveSettings() {
    bool changed = false;
    for (int i = 0; i < sizeof(settings); ++i) {
        byte b = EEPROM.read(i);
        if (b != ((byte *)&settings)[i]) {
            EEPROM.write(i, ((byte *)&settings)[i]);
            changed = true;
        }
    }
    if (changed) EEPROM.commit();
}
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
void loop() {
    TotalTime = millis() - TimerStart; // calculates actual total time
    VolumeCalc();                      // Starts integral function

    // VO2max calculation, tft display and excel csv every 5s --------------
    if ((millis() - TimerVO2calc) > 5000 &&
        pressure < pressThreshold) { // calls vo2maxCalc() for calculation Vo2Max every 5 seconds.
        TimerVO2diff = millis() - TimerVO2calc;
        TimerVO2calc = millis(); // resets the timer

        vo2maxCalc(); // vo2 max function call

        showScreen();
        volumeTotal2 = 0; // resets volume2 to 0 (used for initial 10s sensor test)
        readVoltage();
#ifdef VERBOSE
        DataStream(false); // send csv data via wired com port
#endif
        if (settings.serialbt) {
            DataStream(true); // send csv data via Bluetooth com port
        }
        // how often to broadcast? is 5s too slow?
#ifdef GADGET
        if (settings.sens_on) GadgetWrite(); // Send to sensirion
#endif
        if (settings.cheet_on) VO2Notify(); // Send to GoldenCheetah as VO2 Master

        // send BLE data ----------------
        bpm = int(vo2Max + 0.5);
        heart[1] = (byte)bpm;

        int energyUsed = calTotal * 4.184; // conversion kcal into kJ
        heart[3] = energyUsed / 256;
        heart[2] = energyUsed - (heart[3] * 256);

        delay(100);

        if (settings.heart_on && _BLEClientConnected) {
            heartRateMeasurementCharacteristics.setValue(heart, 8); // set the new value for heartrate
            heartRateMeasurementCharacteristics.notify();           // send a notification that value has changed

            sensorPositionCharacteristic.setValue(hrmPos, 1);
        }
    }

    ReadButtons();
    if (buttonPushCounter1 > 20 && buttonPushCounter2 > 20) ESP.restart();
    if (buttonPushCounter1 == 2) {
        screenNr--;
        screenChanged = 1;
    }
    if (buttonPushCounter2 == 2) {
        screenNr++;
        screenChanged = 1;
    }
    if (screenNr < 1) screenNr = 6;
    if (screenNr > 6) screenNr = 1;
    if (screenChanged == 1) {
        showScreen();
        screenChanged = 0;
    }

    if (millis() - Timer30s > 30000) {
        Timer30s = millis(); // reset timer
        BatteryBT();
    }

    TimerVolCalc = millis(); // part of the integral function to keep calculation volume over time
    // Resets amount of time between calcs
#ifdef GADGET
    if (settings.sens_on) provider.handleDownload();
#endif
}

//----------------------------------------------------------------------------------------------------------
//                  FUNCTIONS
//----------------------------------------------------------------------------------------------------------

#ifdef OXYSENSOR
void CheckInitialO2() {
    // check initial O2 value -----------
    baselineO2 = Oxygen.getOxygenData(COLLECT_NUMBER); // read and check initial VO2%
    bool low = false;

    if (baselineO2 < 20.00) {
        // Clear colour once we're above 20
        while (digitalRead(buttonPin1)) {
            if (!low && baselineO2 < 20) {
                tft.fillScreen(TFT_RED);
                tft.setTextColor(TFT_WHITE, TFT_RED);
                tft.setCursor(5, 5, 4);
                tft.println("INITIAL O2% LOW!");
                tft.setCursor(5, 30, 4);
                tft.println("Wait to continue!");
                low = true;

            } else if (low && baselineO2 >= 20) {
                tft.fillScreen(TFT_GREEN);
                tft.setTextColor(TFT_BLACK, TFT_GREEN);
                tft.setCursor(5, 5, 4);
                tft.println("O2% OK!");
                tft.setCursor(5, 30, 4);
                tft.println("Continue!");
                low = false;
            }

            baselineO2 = Oxygen.getOxygenData(COLLECT_NUMBER);
            tft.setCursor(5, 67, 4);
            tft.print("O2: ");
            tft.print(baselineO2);
            tft.println(" % ");
            tft.setCursor(5, 105, 4);
            tft.println("Continue              >>>");
            delay(500);
        }
        if (baselineO2 < 20.00) baselineO2 = 20.90;
        tft.fillScreen(TFT_BLACK);
        tft.setTextColor(TFT_GREEN, TFT_BLACK);
        tft.setCursor(5, 5, 4);
        tft.println("Initial O2% set to:");
        tft.setTextColor(TFT_WHITE, TFT_BLACK);
        tft.setCursor(5, 55, 4);
        tft.print(baselineO2);
        tft.println(" % ");
        delay(5000);
    }
}
#endif

//--------------------------------------------------

void CheckInitialCO2() { // check initial CO2 value
    readCO2();
    baselineCO2 = co2perc;
    bool high = false;

    if (baselineCO2 > 0.1) {
        while (digitalRead(buttonPin1)) {
            if (!high && baselineCO2 > 0.1) {
                tft.fillScreen(TFT_RED);
                tft.setTextColor(TFT_WHITE, TFT_RED);
                tft.setCursor(5, 5, 4);
                tft.println("INITIAL CO2% HIGH!");
                tft.setCursor(5, 30, 4);
                tft.println("Wait to continue!");
                high = true;
            } else if (high && baselineCO2 <= 0.1) {
                tft.fillScreen(TFT_GREEN);
                tft.setTextColor(TFT_BLACK, TFT_GREEN);
                tft.setCursor(5, 5, 4);
                tft.println("CO2% OK!");
                tft.setCursor(5, 30, 4);
                tft.println("Continue!");
                high = false;
            }

            readCO2();
            baselineCO2 = co2perc;
            tft.setCursor(5, 67, 4);
            tft.print("CO2: ");
            tft.print(baselineCO2, 2);
            tft.println(" % ");
            tft.setCursor(5, 105, 4);
            tft.println("Continue              >>>");
            delay(500);
        }
        if (baselineCO2 > 0.1) baselineCO2 = 0.1;
        tft.fillScreen(TFT_BLACK);
        tft.setTextColor(TFT_GREEN, TFT_BLACK);
        tft.setCursor(5, 5, 4);
        tft.println("Initial CO2 set to:");
        tft.setTextColor(TFT_WHITE, TFT_BLACK);
        tft.setCursor(5, 55, 4);
        tft.print(baselineCO2, 2);
        tft.println("%");
        delay(5000);
    }
}

//--------------------------------------------------

void ConvertTime(float ms) {
    long   inms = long(ms);
    int    h, m, s;
    String strh, strm, strs;
    s = (inms / 1000) % 60;
    m = (inms / 60000) % 60;
    h = (inms / 3600000) % 24;
    strs = String(s);
    if (s < 10) strs = String("0") + strs;
    strm = String(m);
    if (m < 10) strm = String("0") + strm;
    strh = String(h);
    if (h < 10) strh = String("0") + strh;
    TotalTimeMin = String(strh) + String(":") + String(strm) + String(":") + String(strs);
}

//--------------------------------------------------

void VolumeCalc() {

    // Read pressure from Omron D6F PH0025AD1 (or D6F PH0025AD2)
    float pressureraw = mySensor.getPressure();
    pressure = pressure / 2 + pressureraw / 2;

    if (isnan(pressure)) { // isnan = is not a number,  unvalid sensor data
        tft.fillScreen(TFT_RED);
        tft.setTextColor(TFT_WHITE, TFT_RED);
        tft.drawCentreString("VENTURI ERROR!", 120, 55, 4);
    }
    if (pressure > 266) { // upper limit of flow sensor warning
        // tft.fillScreen(TFT_RED);
        tft.setTextColor(TFT_WHITE, TFT_RED);
        tft.drawCentreString("SENSOR LIMIT!", 120, 55, 4);
    }

    if (pressure < 0) pressure = 0;

    if (pressure < pressThreshold && readVE == 1) { // read volumeVE
        readVE = 0;
        DurationVE = millis() - TimerVE;
        BPM = (60 * 1000) / DurationVE;

        TimerVE = millis(); // start timerVE
        volumeExp = volumeTotal;
        volumeTotal = 0; // resets volume for next breath
        volumeVE = volumeExp / DurationVE * 60;
        volumeExp = volumeExp / 1000;
        volumeVEmean = (volumeVEmean * 3 / 4) + (volumeVE / 4); // running mean of one minute volume (VE)
        if (volumeVEmean < 1) volumeVEmean = 0;
        freqVE = 60000 / DurationVE;
        if (volumeVE < 0.1) freqVE = 0;
        freqVEmean = (freqVEmean * 3 / 4) + (freqVE / 4);
        if (freqVEmean < 1) freqVEmean = 0;
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

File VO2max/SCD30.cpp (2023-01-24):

/*
    A library for Grove -

    Copyright (c) 2018 seeed technology co., ltd.
    Author      : Wayen Weng
    Create Time : November 2018
    Change Log  :

    The MIT License (MIT)

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
    THE SOFTWARE IS PROVIDED "AS IS", WITHOUT WARRANTY OF ANY KIND, EXPRESS OR
    IMPLIED, INCLUDING BUT NOT LIMITED TO THE WARRANTIES OF MERCHANTABILITY,
    FITNESS FOR A PARTICULAR PURPOSE AND NONINFRINGEMENT. IN NO EVENT SHALL THE
    AUTHORS OR COPYRIGHT HOLDERS BE LIABLE FOR ANY CLAIM, DAMAGES OR OTHER
    LIABILITY, WHETHER IN AN ACTION OF CONTRACT, TORT OR OTHERWISE, ARISING FROM,
    OUT OF OR IN CONNECTION WITH THE SOFTWARE OR THE USE OR OTHER DEALINGS IN
    THE SOFTWARE.
*/

#include "SCD30.h"

SCD30::SCD30(void) {
    devAddr = SCD30_I2C_ADDRESS;
}

void SCD30::initialize(void) {
    //Set temperature offset。
    //setTemperatureOffset(0);

    setMeasurementInterval(2); // 2 seconds between measurements
    startPeriodicMeasurment(); // start periodic measuments

    //setAutoSelfCalibration(true); // Enable auto-self-calibration
}


void SCD30::setTemperatureOffset(uint16_t offset) {
    writeCommandWithArguments(SCD30_SET_TEMP_OFFSET, offset);
}

bool SCD30::isAvailable(void) {
    return readRegister(SCD30_GET_DATA_READY);
}

void SCD30::setAutoSelfCalibration(bool enable) {
    if (enable) {
        writeCommandWithArguments(SCD30_AUTOMATIC_SELF_CALIBRATION, 1);    //Activate continuous ASC
    } else {
        writeCommandWithArguments(SCD30_AUTOMATIC_SELF_CALIBRATION, 0);    //Deactivate continuous ASC
    }
}

void SCD30::setMeasurementInterval(uint16_t interval) {
    writeCommandWithArguments(SCD30_SET_MEASUREMENT_INTERVAL, interval);
}

void SCD30::startPeriodicMeasurment(void) {
    writeCommandWithArguments(SCD30_CONTINUOUS_MEASUREMENT, 0x0000);
}

void SCD30::stopMeasurement(void) {
    writeCommand(SCD30_STOP_MEASUREMENT);
}

void SCD30::getCarbonDioxideConcentration(float* result) {
    uint8_t buf[18] = { 0 };
    uint32_t co2U32 = 0;
    uint32_t tempU32 = 0;
    uint32_t humU32 = 0;
    float co2Concentration = 0;
    float temperature = 0;
    float humidity = 0;

    writeCommand(SCD30_READ_MEASUREMENT);
    readBuffer(buf, 18);

    co2U32 = (uint32_t)((((uint32_t)buf[0]) << 24) | (((uint32_t)buf[1]) << 16) |
                        (((uint32_t)buf[3]) << 8) | ((uint32_t)buf[4]));

    tempU32 = (uint32_t)((((uint32_t)buf[6]) << 24) | (((uint32_t)buf[7]) << 16) |
                         (((uint32_t)buf[9]) << 8) | ((uint32_t)buf[10]));

    humU32 = (uint32_t)((((uint32_t)buf[12]) << 24) | (((uint32_t)buf[13]) << 16) |
                        (((uint32_t)buf[15]) << 8) | ((uint32_t)buf[16]));

    memcpy(&result[0], &co2U32, sizeof(co2Concentration));
    memcpy(&result[1], &tempU32, sizeof(temperature));
    memcpy(&result[2], &humU32, sizeof(humidity));

}

void SCD30::writeCommand(uint16_t command) {
    Wire.beginTransmission(devAddr);
    Wire.write(command >> 8); // MSB
    Wire.write(command & 0xff); // LSB
    Wire.endTransmission();
}

void SCD30::writeCommandWithArguments(uint16_t command, uint16_t arguments) {
    uint8_t checkSum, buf[5] = { 0 };

    buf[0] = command >> 8;
    buf[1] = command & 0xff;
    buf[2] = arguments >> 8;
    buf[3] = arguments & 0xff;
    checkSum = calculateCrc(&buf[2], 2);
    buf[4] = checkSum;

    writeBuffer(buf, 5);
}

uint16_t SCD30::readRegister(uint16_t address) {
    uint8_t buf[2] = { 0 };

    writeCommand(address);
    readBuffer(buf, 2);

    return ((((uint16_t)buf[0]) << 8) | buf[1]);
}

void SCD30::writeBuffer(uint8_t* data, uint8_t len) {
    Wire.beginTransmission(devAddr);
    Wire.write(data, len);
    Wire.endTransmission();
}

void SCD30::readBuffer(uint8_t* data, uint8_t len) {
    uint8_t i = 0;

    Wire.requestFrom(devAddr, len);
    while (Wire.available()) {
        data[i ++] = Wire.read();
    }
}

uint8_t SCD30::calculateCrc(uint8_t data[], uint8_t len) {
    uint8_t bit, byteCtr, crc = 0xff;

    // calculates 8-Bit checksum with given polynomial
    for (byteCtr = 0; byteCtr < len; byteCtr ++) {
        crc ^= (data[byteCtr]);

        for (bit = 8; bit > 0; -- bit) {
            if (crc & 0x80) {
                crc = (crc << 1) ^ SCD30_POLYNOMIAL;
            } else {
                crc = (crc << 1);
            }
        }
    }

    return crc;
}

SCD30 scd30;

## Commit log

2023-01-25 Add design files and images
    [ComputerCover.3mf, MainBody.3mf, MaskAttachment.3mf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]
2024-03-13 Add STC31 co2 sensor support Add BME280 humidity sensor support
2024-03-15 Fix pressure mistake
2024-12-30 Update libraries use STC31-C CO2 sensor remove local file copies
2024-12-31 Minor CO2 improvements add and test "No O2 sensor" mode remove DEMO mode
2025-01-08 Fix import of SCD30 library
    [VO2max.ino]
2025-01-16 Enable weak filter on STC31
